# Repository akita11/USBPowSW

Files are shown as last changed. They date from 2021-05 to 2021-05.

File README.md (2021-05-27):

# USBPowSW

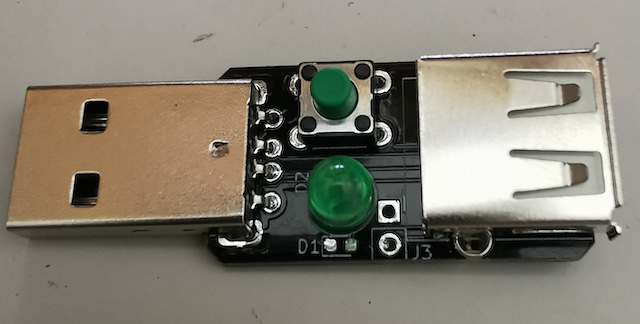
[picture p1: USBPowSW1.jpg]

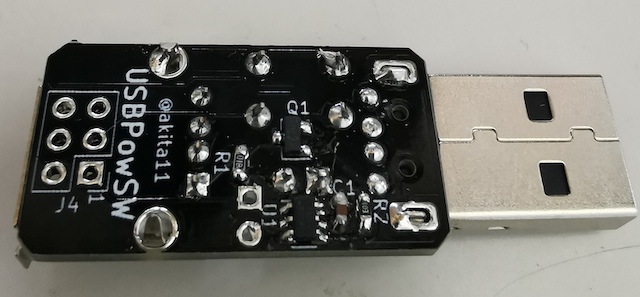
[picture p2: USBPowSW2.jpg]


## これは何？

PCとUSB機器の間のUSB-Aコネクタ(平コネクタ)に接続し、USB機器の電源のON/OFFを行うデバイスです。
マイコン(ATtiny10)が載っていて、ON/OFF制御をプログラムできます。

## 使い方

PCとUSB機器の間の、USB-Aコネクタ(平コネクタ)に接続します。
初期設定ではタクトスイッチを押すごとにON/OFFが切り替わります。（電源ON時にはLEDが点灯します。）

## もっと使い込むには・・・

[回路図](https://github.com/akita11/USBPowSW/blob/main/USBPowSW_schematic.png)と
[プログラム](https://github.com/akita11/USBPowSW/blob/main/USBPowSW.ino)を参考に、
電源ON/OFFを制御するプログラムを書くことができます。
ボード上のタクトスイッチの他、汎用のIOピンを接続する端子をつけることで、そのIOピンの情報も使って制御することができます。

- PB0 : 外部端子に接続（初期状態は未接続）
- PB1 : ボード上のタクトスイッチ（押すと0)
- PB2 : USB電源制御(0=ON、1=OFF）

ATtiny10のプログラム開発や書き込みをArduinoIDEから行う方法は、[kosakalab](https://make.kosakalab.com/make/electronic-work/arduino-ide/arduino_tpi/)などを参考にしてください。(ArduinoIDE1.8.9が必要です)
また書き込みは、この方法や、Atmelマイコンの書き込み機(AVR-ISP mkIIなど)を使用してください。
（通常のArduinoのように、PCと接続して直接の書き込みはできません）

## Author

Junichi Akita (akita@ifdl.jp, @akita11)

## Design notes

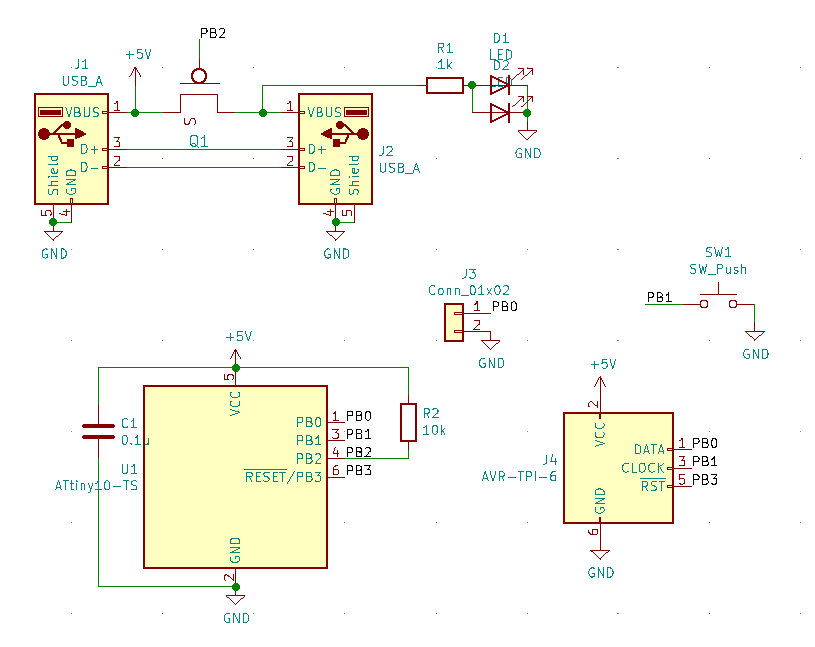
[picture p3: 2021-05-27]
USBPowSW_schematic.png

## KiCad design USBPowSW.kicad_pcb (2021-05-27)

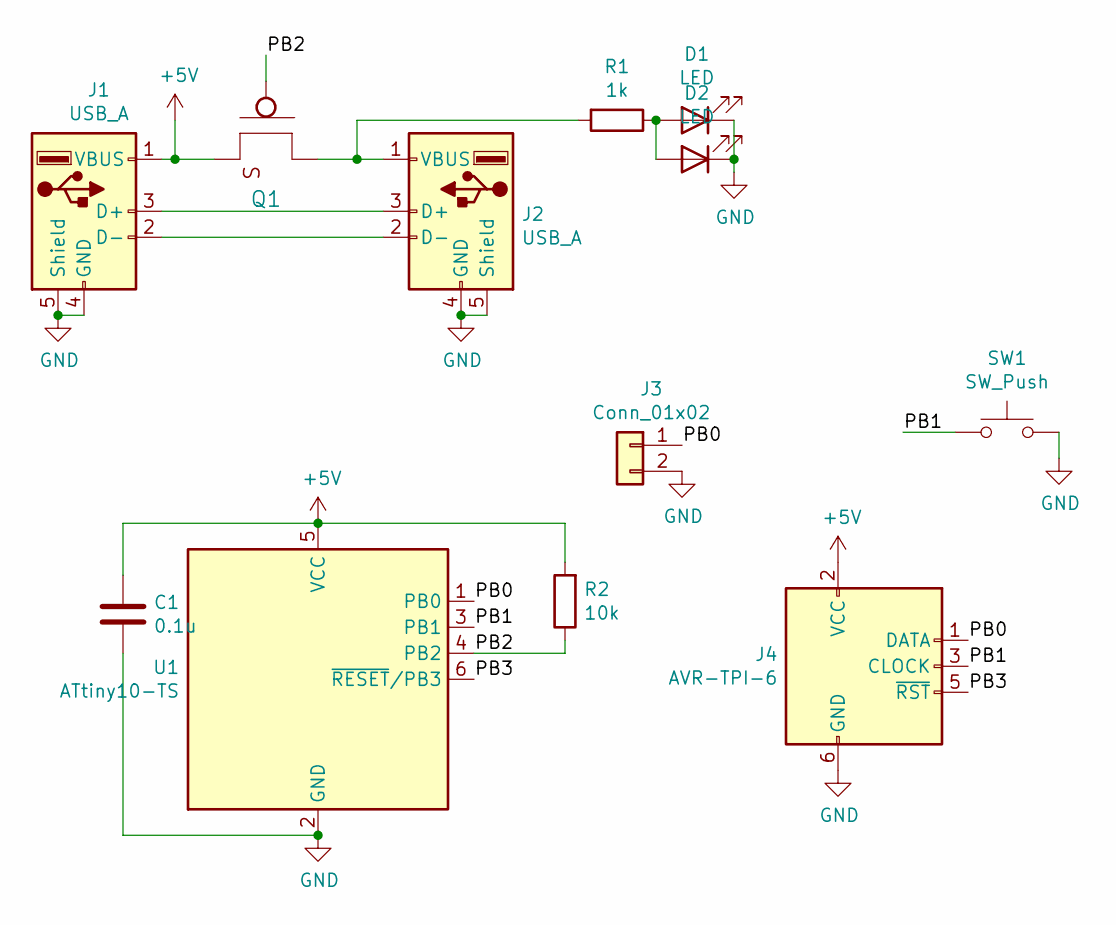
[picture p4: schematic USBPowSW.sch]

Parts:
C1: 0.1u; C_0603_1608Metric
D1: LED; LED_0603_1608Metric
D2: LED; LED_D5.0mm_Clear
J1: USB_A; USB-A_plug
J2: USB_A; USB_A_Molex_67643_Horizontal
J3: Conn_01x02; PinSocket_1x02_P2.54mm_Vertical
J4: AVR-TPI-6; PinHeader_2x03_P2.54mm_Vertical
Q1: TR_PMOS_IRLML6402; SOT-23
R1: 1k; R_0603_1608Metric
R2: 10k; R_0603_1608Metric
SW1: SW_Push; SW_PUSH_6mm
U1: ATtiny10-TS; SOT-23-6

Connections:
+5V: C1.1, J1.1 (VBUS), J4.2 (VCC), Q1.2 (S), R2.2, U1.5 (VCC)
/PB0: J3.1, J4.1 (DATA), U1.1 (PB0)
/PB1: J4.3 (CLOCK), SW1.1, U1.3 (PB1)
/PB2: Q1.1 (G), R2.1, U1.4 (PB2)
/PB3: J4.5 (~RST), U1.6 (~RESET~/PB3)
GND: C1.2, D1.1 (K), D2.1 (K), J1.4 (GND), J1.5 (Shield), J2.4 (GND), J2.5 (Shield), J3.2, J4.6 (GND), SW1.2, U1.2 (GND)
unnamed: D1.2 (A), D2.2 (A), R1.1
unnamed: J1.2 (D-), J2.2 (D-)
unnamed: J1.3 (D+), J2.3 (D+)
unnamed: J2.1 (VBUS), Q1.3 (D), R1.2

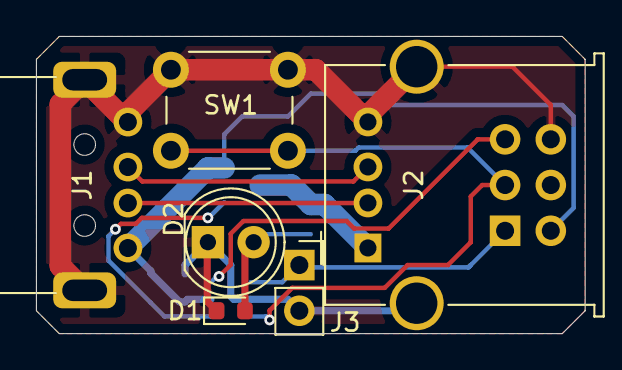
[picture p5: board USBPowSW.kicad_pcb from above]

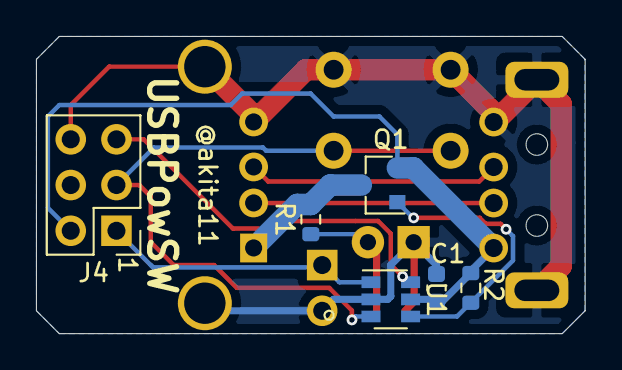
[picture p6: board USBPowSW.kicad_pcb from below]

Board: 2 copper layers, 30.5 x 16.5 mm, 12 parts (6 on the bottom side), 10 nets.

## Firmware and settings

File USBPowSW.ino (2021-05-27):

#include <avr/wdt.h>
#include <avr/sleep.h>

#define AIN    0 // p1
#define SW     1 // p3
#define POWb   2 // p4
// p2=GND, p5=VCC

void setup() {
  pinMode(SW, INPUT_PULLUP);
  digitalWrite(POWb, 1);
  pinMode(POWb, OUTPUT);
  USBPow(0);
}

int st = 0;

void loop() {
  if (digitalRead(SW) == 0){
    st = 1 - st;
    USBPow(st);
    while(digitalRead(SW) == 0) delay(10);
  }
}

void USBPow(int state)
{
  if (state == 1) digitalWrite(POWb, 0);
  else digitalWrite(POWb, 1);
}
